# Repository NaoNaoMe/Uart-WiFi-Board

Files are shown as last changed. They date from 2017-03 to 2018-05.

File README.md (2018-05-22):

Uart WiFi Board
=========

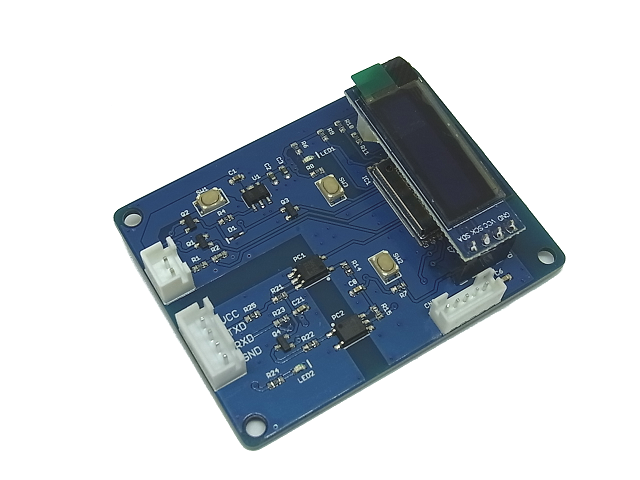
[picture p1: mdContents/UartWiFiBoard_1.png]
Uart WiFi Board
[  
*Uart WiFi Board(SKU-3849)*](https://international.switch-science.com/catalog/3849/)

## Uart WiFi Board has been launched! It is available in [the Switch Science store](https://international.switch-science.com/catalog/3849/).

The Uart WiFi Board designed as the transparent WiFi-serial bridge.  
There are some updates from the former Uart WiFi Board.  
 - The 128x32 pixels SSD1306 OLED display
 - The 3 user switches(a switch used as power switch too)

Thanks to add the 128x32 pixels OLED display, we can show IP address, SSID and Serial BaudRate.  
You don't need remember IP address and Baud Rate, you can see them in the display.
The Uart WiFi Board can be programmed using the Arduino IDE.

### Some highlights of the Uart WiFi Board:
 1. Main core: ESP-WROOM-02(ESP8266).
 2. Voltage regulator(3.3V) with control pin.
 3. Opto-isolated UART interface(Uart interface circuit accepts 3.3V and 5.0V).
 4. On board WiFi-controller can use following functions.
 	- LED1(IO2), SW1(IO12/POW_ON), SW2(IO16) and SW3(IO13)
 	- Control voltage regulator's control pin connected to "IO14" H:Enable L:Disable(normally)
 	- Voltage detection circuit(for CN1) connected to "TOUT"
 5. Measures 50mm x 60mm x 20mm

#### Some highlights of the Sample software:
 1. Totally transparent WiFi-serial bridge.
 2. IP address, SSID, Serial baud-rate and input-voltage can be displayed.
 3. Low voltage detection.
 
Sample software use the [esp8266-oled-ssd1306](https://github.com/ThingPulse/esp8266-oled-ssd1306) library.

Repository Contents
-------------------
* **/Hardware** - All Eagle design files (.brd, .sch)
* **/Software** - Software files for this hardware

Description(Pin Interfaces)
-------------------
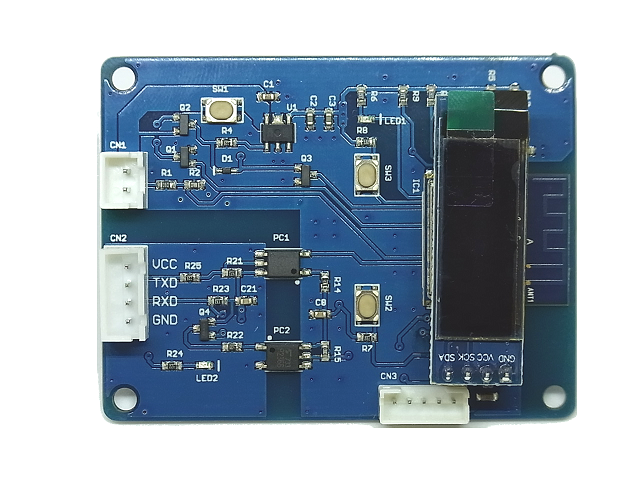
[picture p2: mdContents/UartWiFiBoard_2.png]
TopView


### CN1(Primarily) Pin Descriptions:
This connector is the supply voltage.

| Pin | Name | Description |
| --- | ---- | --- |
| 1 | VBAT | Up to 12.0VDC convert to 3.3VDC |
| 2 | GND  | GND	 |

### CN3(Primarily) Pin Descriptions:
This connector is for uploading software to WiFi-controller.  
To be selected BOOT MODE before supply voltage when you upload software.

| Pin | Name | Description |
| --- | ---- | --- |
| 1 | VCC  | 3.3VDC |
| 2 | TX | UART TX	 |
| 3 | RX | UART RX	 |
| 4 | GND  | GND	 |
| 5 | BOOT | Connected to "IO0" H:Flash boot(normally) L:UART download |

### CN2(Secondary) Pin Descriptions:
This connector is for your target board UART-interface.

| Pin | Name | Description |
| --- | ---- | --- |
| 1 | VIN  | 2.7VDC to 5.5VDC |
| 2 | TX | UART TX(Open collector output)	 |
| 3 | RX | UART RX	 |
| 4 | GND  | GND	 |

How to upload program
-------------------
See [this page](UploadProgram.md).

How to use the Uart WiFi Board
-------------------
An example is [here](Instructions.md).

License
-------------------
The repository is released under [Creative Commons ShareAlike 4.0 International](https://creativecommons.org/licenses/by-sa/4.0/).

Distributed as-is; no warranty is given.

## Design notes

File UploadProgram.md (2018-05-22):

Upload a program for the Uart WiFi Board
========================================

First of all
--------------
You will need the following items for uploading program.
 - FTDI Breakout Board(3.3V)
 - [FTDI Breakout Adapter](https://github.com/NaoNaoMe/FTDI-Breakout-Adapter)
 - [Programming cable](https://github.com/NaoNaoMe/FTDI-Breakout-Adapter/tree/master/Cables)

Hardware Setup
--------------
Connect the FTDI Breakout to the FTDI Breakout Adapter with the Programming cable like the following figure.
The JP1 on the FTDI Breakout Adapter is jumped to GND. The JP2 is not jumped.
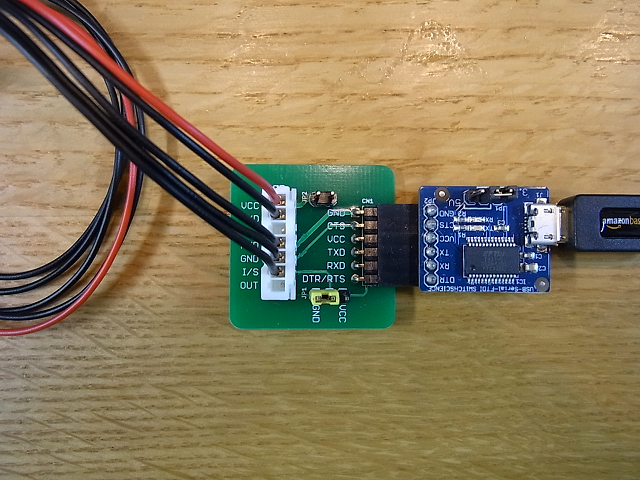
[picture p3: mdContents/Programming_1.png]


Upload a program
--------------
Plug the Programming cable into the CN2 on the Uart WiFi Board.  
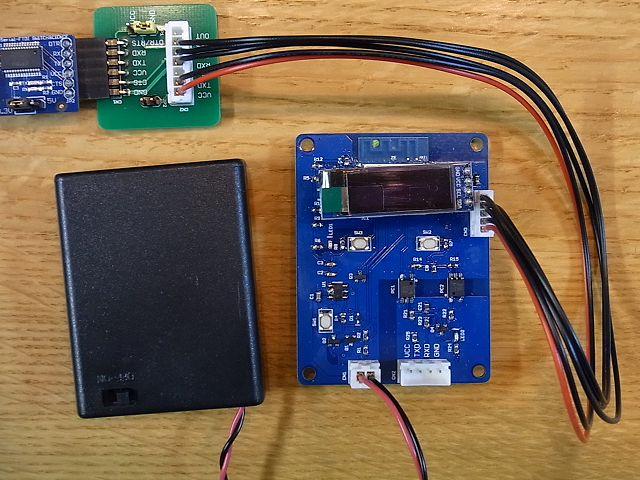
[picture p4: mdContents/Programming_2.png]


### Sample software
If you want to try [sample software](), you can modify the following configurations.
```
const char* ssid = "TestSSID0123";
const char* password = "TestEncryptionKey0123";

int serialSpeedIndex = 0;   //9600bps
```

### Arduino IDE
Open up [the sample software](https://github.com/NaoNaoMe/Uart-WiFi-Board/tree/with-display/Software/UartWiFiBridge) or your own software in the Arduino IDE.  
The board selection and programming configuration are in the figure below.  
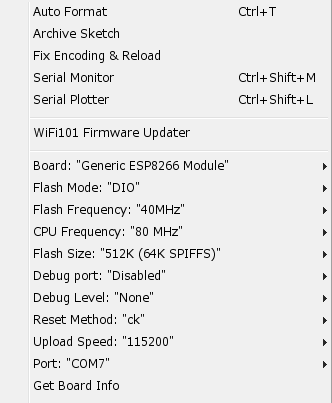
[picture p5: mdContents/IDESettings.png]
Settings
  

Press SW1 button in order to turn on the Uart WiFi Board. Please hold on SW1 button while uploading software.  
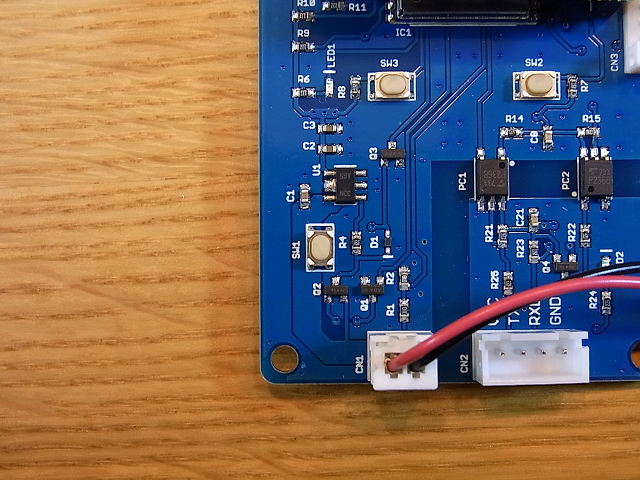
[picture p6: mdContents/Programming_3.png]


Click the Upload button in the IDE. Wait a few seconds.  
The message "Done uploading." will appear in the status bar, unplug the Programming cable from the Uart WiFi Board.

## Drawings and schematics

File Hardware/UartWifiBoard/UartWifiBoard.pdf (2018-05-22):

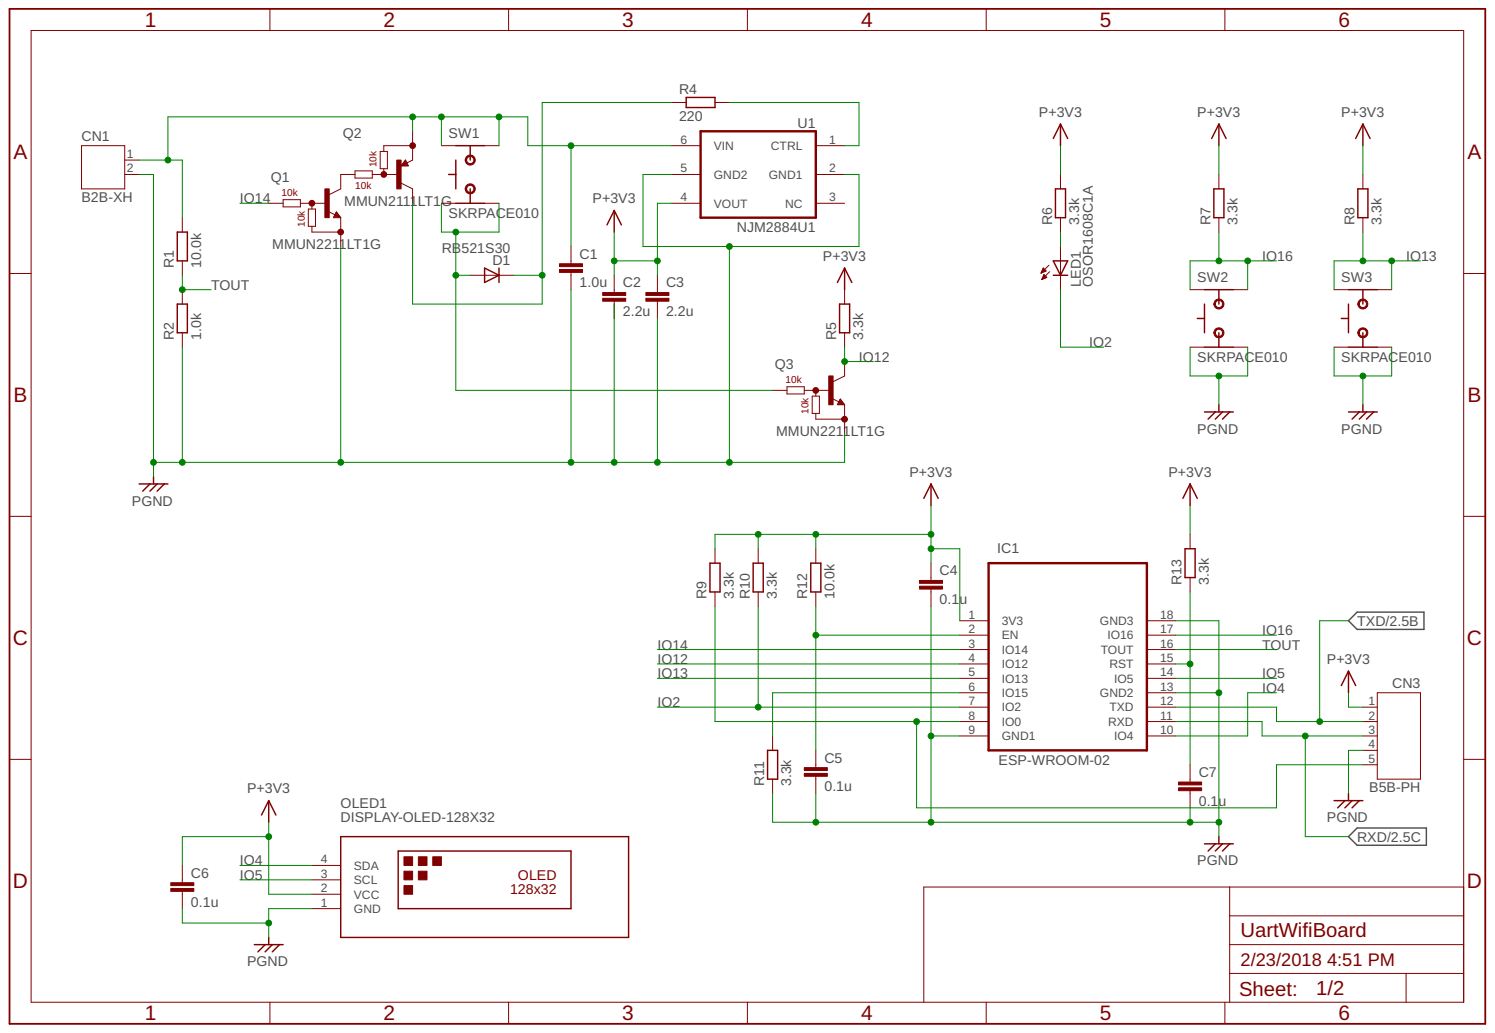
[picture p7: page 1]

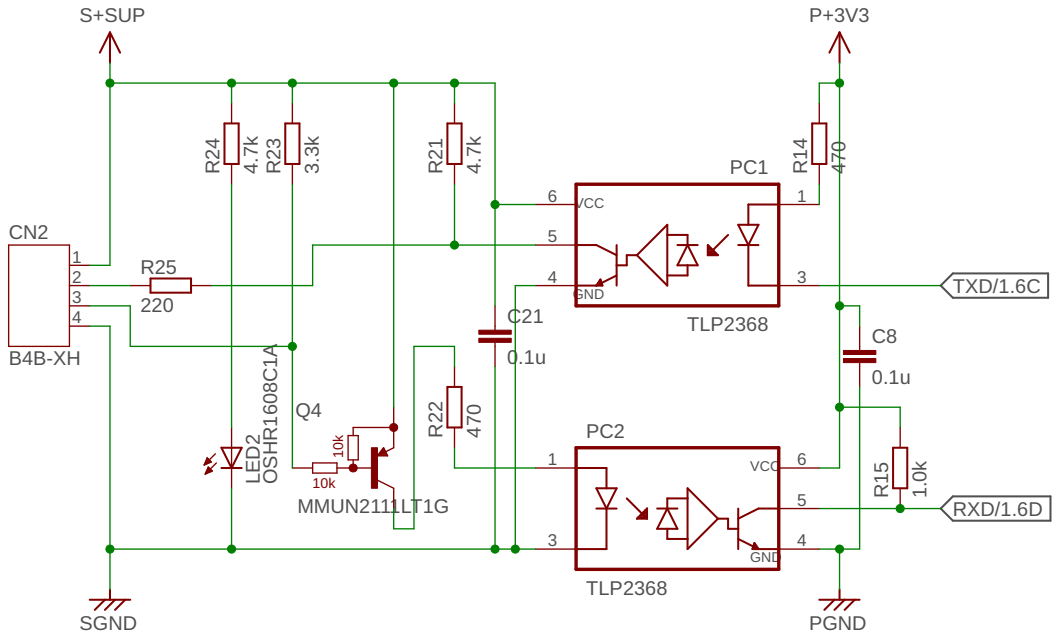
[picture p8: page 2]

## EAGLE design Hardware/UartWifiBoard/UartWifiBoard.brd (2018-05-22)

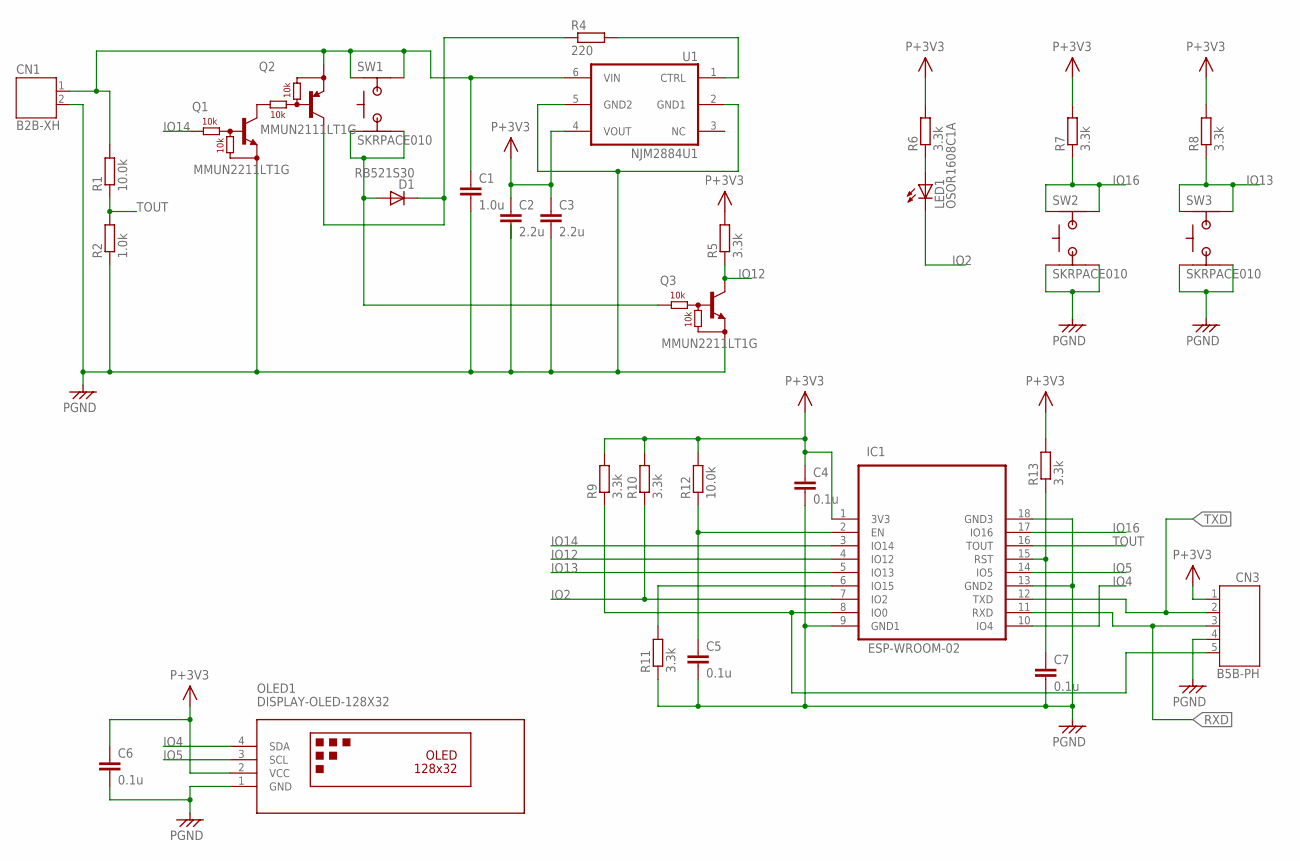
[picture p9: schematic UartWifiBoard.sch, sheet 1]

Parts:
C1: 1.0u; C0603
C2, C3: 2.2u; C0603
C4, C5, C6, C7: 0.1u; C0603
CN1: B2B-XH
CN3: B5B-PH
D1: RB521S30; SOD-523F
IC1: ESP-WROOM-02
LED1: OSOR1608C1A; LED0603SMD
OLED1: DISPLAY-OLED-128X32
Q1, Q3: MMUN2211LT1G; SOT-23
Q2: MMUN2111LT1G; SOT-23
R1, R12: 10.0k; R0603
R2: 1.0k; R0603
R4: 220; R0603
R5, R6, R7, R8, R9, R10, R11, R13: 3.3k; R0603
SW1, SW2, SW3: SKRPACE010; SKRP
U1: NJM2884U1; SOT89-5

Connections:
IO0: CN3.5, IC1.8 (IO0), R9.1
IO2: IC1.7 (IO2), LED1.C, R10.1
IO4: IC1.10 (IO4), OLED1.4 (SDA)
IO5: IC1.14 (IO5), OLED1.3 (SCL)
IO12: IC1.4 (IO12), Q3.P$3 (C), R5.1
IO13: IC1.5 (IO13), R8.1, SW3.1, SW3.2
IO14: IC1.3 (IO14), Q1.P$1 (B)
IO15: IC1.6 (IO15), R11.2
IO16: IC1.17 (IO16), R7.1, SW2.1, SW2.2
unnamed: Q1.P$3 (C), Q2.P$1 (B)
unnamed: R4.2, U1.1 (CTRL)
unnamed: C1.1, CN1.1, Q2.P$2 (E), R1.2, SW1.1, SW1.2, U1.6 (VIN)
unnamed: D1.C, Q2.P$3 (C), R4.1
unnamed: D1.A, Q3.P$1 (B), SW1.3, SW1.4
unnamed: C5.1, IC1.2 (EN), R12.1
unnamed: LED1.A, R6.1
P+3V3: C2.1, C3.1, C4.1, C6.1, CN3.1, IC1.1 (3V3), OLED1.2 (VCC), R5.2, R6.2, R7.2, R8.2, R9.2, R10.2, R12.2, R13.2, U1.4 (VOUT); also elsewhere on the board
PGND: C1.2, C2.2, C3.2, C4.2, C5.2, C6.2, C7.2, CN1.2, CN3.4, IC1.9 (GND1), IC1.13 (GND2), IC1.18 (GND3), OLED1.1 (GND), Q1.P$2 (E), Q3.P$2 (E), R2.1, R11.1, SW2.3, SW2.4, SW3.3, SW3.4, U1.2 (GND1), U1.5 (GND2); also elsewhere on the board
RST: C7.1, IC1.15 (RST), R13.1
RXD: CN3.3, IC1.11 (RXD); also elsewhere on the board
TOUT: IC1.16 (TOUT), R1.1, R2.2
TXD: CN3.2, IC1.12 (TXD); also elsewhere on the board

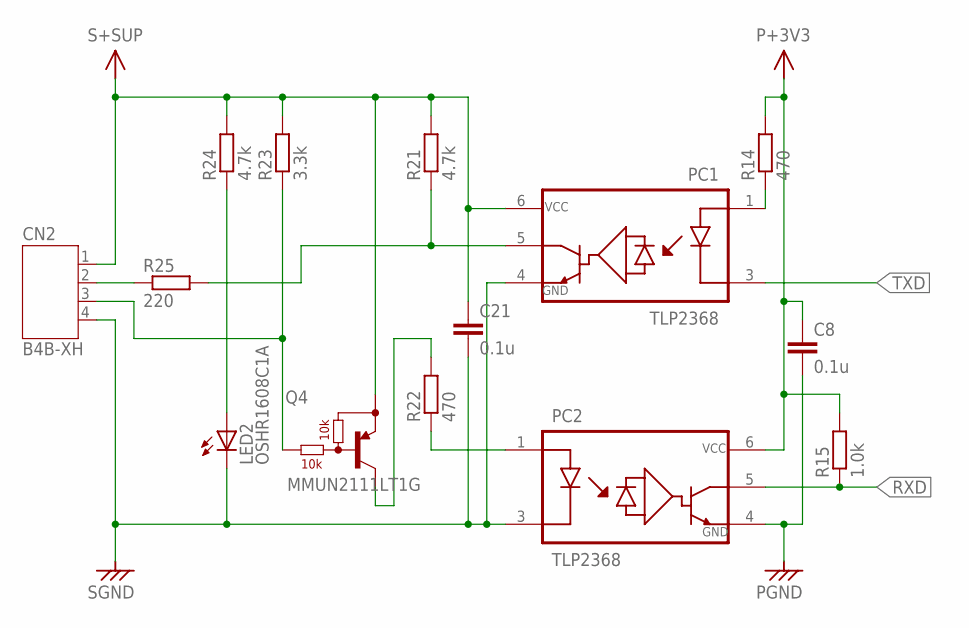
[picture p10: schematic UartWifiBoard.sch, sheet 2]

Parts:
C8, C21: 0.1u; C0603
CN2: B4B-XH
LED2: OSHR1608C1A; LED0603SMD
PC1, PC2: TLP2368; SO6-5PIN
Q4: MMUN2111LT1G; SOT-23
R14, R22: 470; R0603
R15: 1.0k; R0603
R21, R24: 4.7k; R0603
R23: 3.3k; R0603
R25: 220; R0603

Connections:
unnamed: Q4.P$3 (C), R22.2
unnamed: CN2.3, Q4.P$1 (B), R23.1
unnamed: PC2.1 (A), R22.1
unnamed: PC1.5 (VO), R21.1, R25.2
unnamed: CN2.2, R25.1
unnamed: LED2.A, R24.1
unnamed: PC1.1 (A), R14.1
P+3V3: C8.1, PC2.6 (VCC), R14.2, R15.2; also elsewhere on the board
PGND: C8.2, PC2.4 (GND); also elsewhere on the board
RXD: PC2.5 (VO), R15.1; also elsewhere on the board
S+SUP: C21.1, CN2.1, PC1.6 (VCC), Q4.P$2 (E), R21.2, R23.2, R24.2
SGND: C21.2, CN2.4, LED2.C, PC1.4 (GND), PC2.3 (K)
TXD: PC1.3 (K); also elsewhere on the board

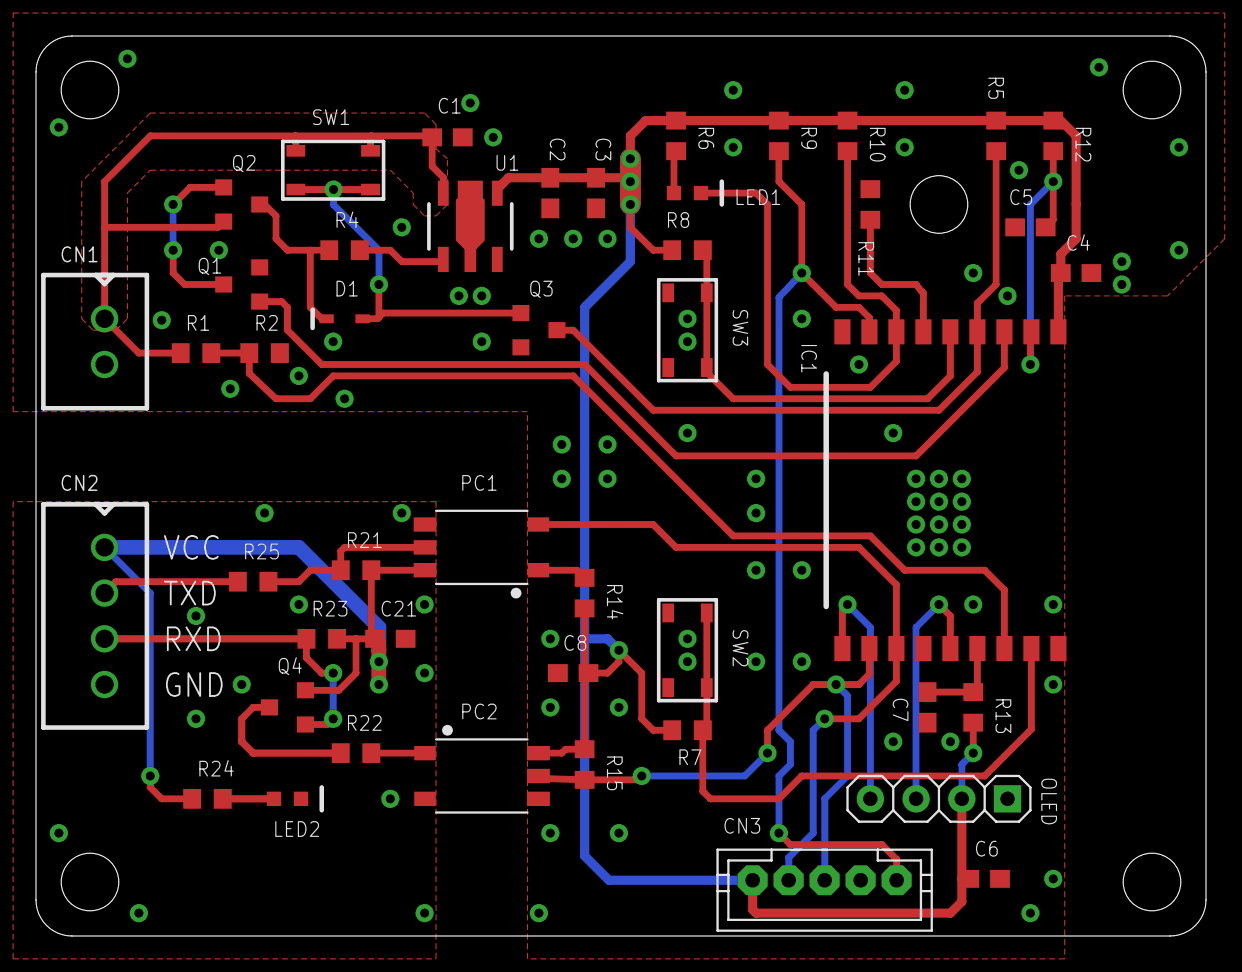
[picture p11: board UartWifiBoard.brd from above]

Board: 2 copper layers, 65.0 x 50.0 mm, 46 parts (0 on the bottom side), 31 nets.

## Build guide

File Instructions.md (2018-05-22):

How to use the Uart WiFi Board
========================================

The easiest way is using micro controller board which has arduino form-factor pinout.  

First of all
--------------
The Uart WiFi Board is programmed [Uart WiFi Bridge software](https://github.com/NaoNaoMe/Uart-WiFi-Board/tree/with-display/Software/UartWiFiBridge).  
You will need the following items for uploading program.
 - Arduino or Arduino form-factor board
 - [Communication Shield](https://github.com/NaoNaoMe/Communication-Shield)
 - [Communication cable](https://github.com/NaoNaoMe/Communication-Shield/tree/master/Cables)
 - PuTTY

Sample software for your board
--------------
These software serial configurations are 9600 bauds, 8-bit data and no parity.

Arduino
```
void setup() {
  Serial.begin(9600);
  Serial.println("Hello World !");
}

void loop() {
  if (Serial.available() > 0) {
    Serial.write(Serial.read() + 1);
  }
}
```

Mbed
```
#include "mbed.h"

Serial pc(D1, D0);  //for FRDM boards
//Serial pc(SERIAL_TX, SERIAL_RX);  // for Nucleo boards

int main() {
  pc.printf("Hello World !\n");
  while(1) {
    pc.putc(pc.getc() + 1);
  }
}
```

Hardware Setup
--------------
Attach the Communication shield in your micro-controller board. 

The Arduino UNO.

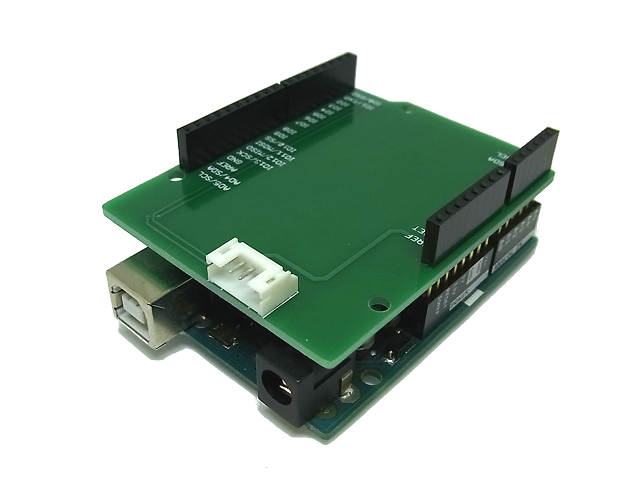
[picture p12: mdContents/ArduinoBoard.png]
Arduino


The Nucleo board.  
The Nucleo boards need some tricks about smd parts.  
All you need is that SB13 and SB14 are OFF, SB62 and SB63 are ON.

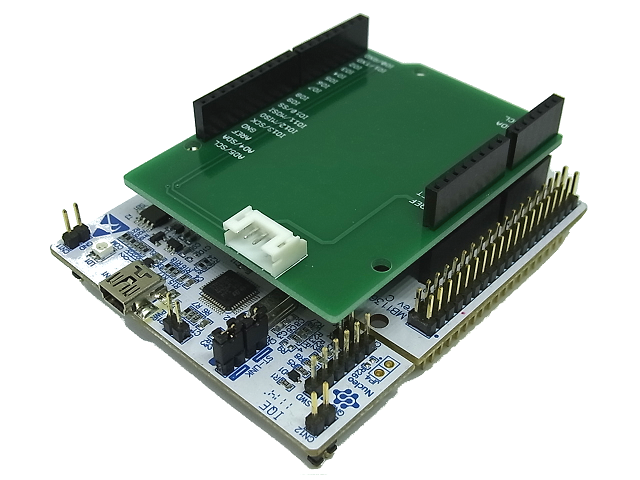
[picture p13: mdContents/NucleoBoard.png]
Nucleo


The FRDM board.

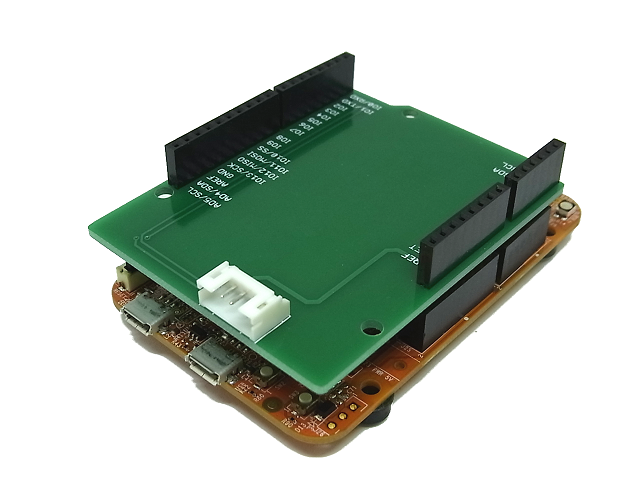
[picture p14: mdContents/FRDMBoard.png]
FRDM


Connect the Communication shield to the Uart WiFi Board with the Communication cable like the following figure(E.g. Arduino).

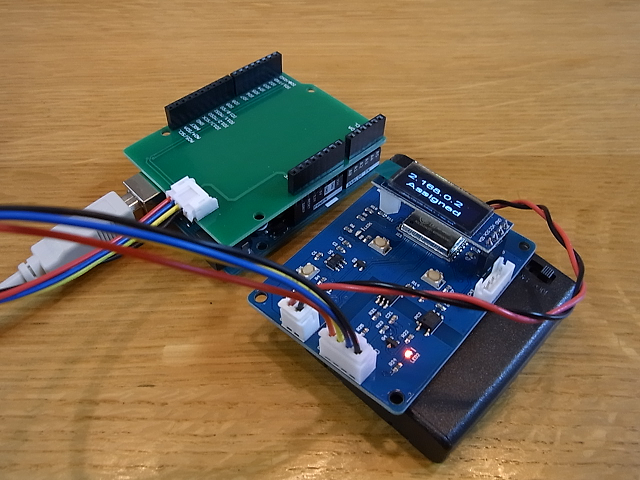
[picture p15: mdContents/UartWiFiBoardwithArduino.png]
Sample


Communication with your board
--------------
Press the SW1 button to turn on the Uart WiFi Board.  
The Uart WiFi Board is started, you can check SSID, IP address and baud rate on the display by pressing SW3 button.  

Execute PuTTY to start the application and type the IP address of the Uart WiFi Board in the Host Name field.  
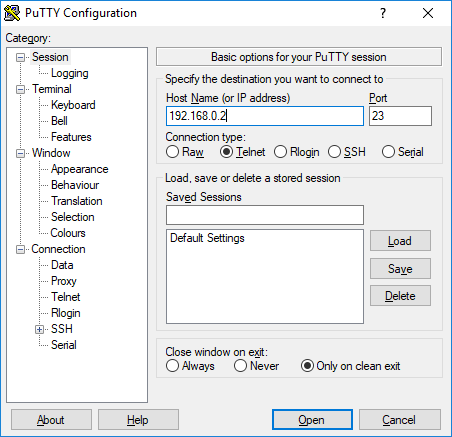
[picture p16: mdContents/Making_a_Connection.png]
Connection


Turn on your board. You can see "Hello World !" in the PuTTY application.
When you type a character, your board return a character like following.  
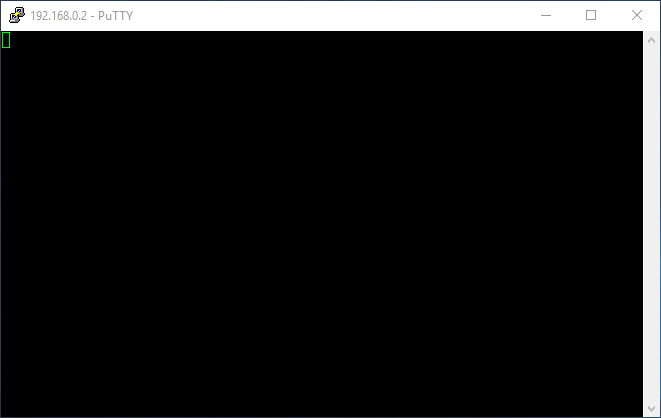
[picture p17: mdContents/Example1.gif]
Example


It looks like the cursor acts weird. That's because adding 1 to CR(0x0D) and LF(0x0A), they are changed to SO(0x0E) and VT(0x0B).

It doesn't work?
--------------
Please check bitrate on your board.  
In addition, you need to make sure that your computer are on the same network segment as the Uart WiFi Board.

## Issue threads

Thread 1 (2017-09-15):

Will it work for ESP 12 module?

Sumgit91, 2017-09-15:
Hi iam using ESP12 module and i need to transmit data from a sensor module which transmits data serially to appear in an interactive web page (which should act like a terminal program), will this code work for me?

NaoNaoMe, 2017-09-19:
If you connect esp-module to your sensor module, this code is not appropriate.
Almost all sensor modules communicate with I2C or SPI interface. This project only provide a UART interface.

Closed 2018-12-20.

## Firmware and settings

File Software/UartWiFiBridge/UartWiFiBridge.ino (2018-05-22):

//******************************************************************************
// UartWiFiBridge
// Note
// Totally transparent UART-WiFi bridge.
// This sketch adapts to UartWiFiBoard project.
//******************************************************************************

#include <ESP8266WiFi.h>
#include <Wire.h>
#include <EEPROM.h>
#include "oled.h"

#define POW_BUTTON_PIN 12   //SW1
#define LEFT_BUTTON_PIN 13  //SW3
#define RIGHT_BUTTON_PIN 16 //SW2

#define STATUS_LED_PIN 2  //LED1
#define REG_CTRL_PIN 14   //U1

#define SERIAL_ARRAY_SIZE 5

enum BoardCondition{
  CHECK_OLED_DEVICE = 0,
  BOARD_OPENING,
  WIFI_CONNECTION_WAITING,
  WIFI_CONNECTION_SUCCESS,
  BOARD_LV_DETECTED,
  BOARD_CLOSING
};

enum BoardProperty{
  SHOW_NOTHING = 0,
  SHOW_CONNECTED_SSID,
  SHOW_ASSIGNED_IP,
  SHOW_BAUDRATE,
  SHOW_BATTERY_VOLTAGE,
  SHOW_BLANK
};

enum SwitchState{
  SW_NOTHING = 0,
  SW_SHORT_PUSH,
  SW_LONG_PUSH
};

enum LvState{
  LV_NOTHING = 0,
  LV_DETECTED,
  LV_QUIT
};

#define RESISTOR_VALUE_R1  (float)10000  //10.0k ohm
#define RESISTOR_VALUE_R2  (float) 1000  // 1.0k ohm
#define IMPEDANCE_VALUE_AD (float)20000  //20.0k ohm

#define RESISTOR_VALUE_H    RESISTOR_VALUE_R1
#define RESISTOR_VALUE_L    (1/((1/RESISTOR_VALUE_R2) + (1/IMPEDANCE_VALUE_AD)))

#define BATT_GAIN_MAX       (float)100
#define BATT_GAIN_DEFAULT   (float)((RESISTOR_VALUE_L * 1024) / (RESISTOR_VALUE_H + RESISTOR_VALUE_L))
#define BATT_GAIN_MIN       (float)80

#define LV_DETECT_VOLTAGE     3.5f    // Low voltage value(3.5V)
#define LV_QUIT_VOLTAGE       3.3f    // Low voltage value(3.3V)

#define CALIBRATION_REF       5.0f    // Battery voltage value(5.0V)

//#define STATIC_IP_ADDR

const String SerialSpeeds[SERIAL_ARRAY_SIZE] = {
  "9600",
  "19200",
  "38400",
  "57600",
  "115200"
};

OLED OLEDModule;

const char VersionName[] = "UWB-Sample";
const char VersionNumber[] = "1.0.0";

const char* ssid = "TestSSID0123";
const char* password = "TestEncryptionKey0123";

#ifdef STATIC_IP_ADDR
IPAddress staticIP(192,168,0,25);
IPAddress gateway(192,168,0,1);
IPAddress subnet(255,255,255,0);
#endif

WiFiServer localServer(23); //Port number must be set
WiFiClient localClient;

int serialSpeedIndex = 0;
float BatteryCalcGain = BATT_GAIN_DEFAULT;
int   BattryVoltAD  = 0;
float BattryVoltage = 0;

LvState detectLowVoltage(){
  static unsigned long previousMillis = 0;
  static int lvDetectCnt = 0;
  static int lvQuitCnt = 0;
  static LvState lowVoltageState = LV_NOTHING;
  
  unsigned long currentMillis = millis();

  if ((currentMillis - previousMillis) >= 100) {
    previousMillis = currentMillis;

    //check Battery voltage
    BattryVoltAD = analogRead(A0);
    BattryVoltage = (float)BattryVoltAD / BatteryCalcGain;
    
    if( BattryVoltage < LV_DETECT_VOLTAGE ) {
      lvDetectCnt++;
    }
    else {
      lvDetectCnt = 0;      
    }
  
    if( lvDetectCnt > 10 ) {
      lvDetectCnt = 10;
      lowVoltageState = LV_DETECTED;
    }
    
    if( BattryVoltage < LV_QUIT_VOLTAGE ) {
      lvQuitCnt++;
    }
    else {
      lvQuitCnt = 0;      
    }
  
    if( lvQuitCnt > 10 ) {
      lvQuitCnt = 10;
      lowVoltageState = LV_QUIT;
    }
  }
  
  return lowVoltageState;
}

bool IntervalTiming(int intervalCount){
  static unsigned long previousMillis = 0;

  bool timeupFlg = false;
  
  unsigned long currentMillis = millis();
  
  if ((currentMillis - previousMillis) >= intervalCount) {
    previousMillis = currentMillis;
    timeupFlg = true;

  }
  
  return timeupFlg;
}


SwitchState detectLeftButton(){
  static unsigned long previousMillis = 0;
  static SwitchState swState = SW_NOTHING;
  SwitchState retState = SW_NOTHING;
  unsigned long currentMillis = millis();
  
  int val = digitalRead(LEFT_BUTTON_PIN);
  if(val == LOW)
  {
    if ((currentMillis - previousMillis) > 1000) {
      if( swState != SW_LONG_PUSH ){
        swState = SW_LONG_PUSH;
        retState = SW_LONG_PUSH;
        
      }

    }
    else if ((currentMillis - previousMillis) > 100) {
      swState = SW_SHORT_PUSH;

    }
  }
  else
  {
    if(swState == SW_SHORT_PUSH) {
      retState = SW_SHORT_PUSH;
      swState = SW_NOTHING;
      
    }

    previousMillis = currentMillis;
    
  }

  return retState;
}


SwitchState detectRightButton(){
  static unsigned long previousMillis = 0;
  static SwitchState swState = SW_NOTHING;
  SwitchState retState = SW_NOTHING;
  unsigned long currentMillis = millis();
  
  int val = digitalRead(RIGHT_BUTTON_PIN);
  if(val == LOW)
  {
    if ((currentMillis - previousMillis) > 1000) {
      if( swState != SW_LONG_PUSH ){
        swState = SW_LONG_PUSH;
        retState = SW_LONG_PUSH;
        
      }

    }
    else if ((currentMillis - previousMillis) > 100) {
      swState = SW_SHORT_PUSH;

    }
  }
  else
  {
    if(swState == SW_SHORT_PUSH) {
      retState = SW_SHORT_PUSH;
      swState = SW_NOTHING;
      
    }

    previousMillis = currentMillis;
    
  }

  return retState;
}

bool detectPowButton(){
  static unsigned long previousMillis = 0;
  bool retFlg = false;
  unsigned long currentMillis = millis();
  
  int val = digitalRead(POW_BUTTON_PIN);
  if(val == LOW)
  {
    if (currentMillis - previousMillis > 3000) {
      previousMillis = currentMillis;
      retFlg = true;
    }
  }
  else
  {
    previousMillis = currentMillis;
    
  }

  return retFlg;
}

String appendString(String stringOne, String stringTwo ) {
  String retString;
  retString = stringOne.concat(stringTwo);
  return stringOne;
}

void dataExchange() {
  static unsigned long previousMillis = 0;
  
  unsigned long currentMillis = millis();
  if ((currentMillis - previousMillis) >= 50) {
    previousMillis = currentMillis;
    size_t bufLength = 0;
    
    //check if there are any new clients
    if (localServer.hasClient()){
      if (!localClient.connected()){
        if(localClient){
          localClient.stop();
        }
        localClient = localServer.available();
      }
    }
    
    //check a client to bridge UART
    if (localClient && localClient.connected()){
      if(localClient.available()){
        bufLength = localClient.available();
        uint8_t sbuf[bufLength];
        localClient.readBytes(sbuf, bufLength);
        Serial.write(sbuf, bufLength);
      }
      digitalWrite(STATUS_LED_PIN, LOW);
    }
    else{
      digitalWrite(STATUS_LED_PIN, HIGH);
      
    }

    //check UART to bridge WiFi
    if(Serial.available()){
      bufLength = Serial.available();
      uint8_t sbuf[bufLength];
      Serial.readBytes(sbuf, bufLength);
      if (localClient && localClient.connected()){
        localClient.write(sbuf, bufLength);
      }
    }
  }
}

bool ScanI2CDevices(byte address) {
  bool retflg =false;
  Wire.beginTransmission(address);
  byte error = Wire.endTransmission();
  if (error == 0) {
    retflg = true;
    
  }
  return retflg;
}

float ReadCalibration(float input) {
  float output = input;
  float gain = 0;
  byte tmp = 0;
  uint32_t value = 0;
  
  tmp = EEPROM.read(3);
  value |= (uint32_t)tmp;
  value = (value << 8) & 0xFFFFFF00;
  tmp = EEPROM.read(2);
  value |= (uint32_t)tmp;
  value = (value << 8) & 0xFFFFFF00;
  tmp = EEPROM.read(1);
  value |= (uint32_t)tmp;
  value = (value << 8) & 0xFFFFFF00;
  tmp = EEPROM.read(0);
  value |= (uint32_t)tmp;

  if(value != 0xFFFFFFFF) {
    gain = *(float *)&value;
    if( (gain <  BATT_GAIN_MAX) &&
        (gain >= BATT_GAIN_MIN) ) {
      output = gain;
    }
  }
  
  return output;
}

float WriteCalibration(float input) {
  float output = input;
  byte tmp = 0;
  uint32_t value = 0;

  if( (input >= BATT_GAIN_MAX) ||
      (input <  BATT_GAIN_MIN) ) {
    return output;
  }
  
  value = *(uint32_t *)&input;
  tmp = (byte)(value & 0x000000FF); 
  value = value >> 8;
  EEPROM.write(0, tmp);
  tmp = (byte)(value & 0x000000FF); 
  value = value >> 8;
  EEPROM.write(1, tmp);
  tmp = (byte)(value & 0x000000FF); 
  value = value >> 8;
  EEPROM.write(2, tmp);
  tmp = (byte)(value & 0x000000FF); 
  EEPROM.write(3, tmp);

  EEPROM.commit();
  
  return output;
}

void setup() {
  digitalWrite(REG_CTRL_PIN, HIGH);   // Enable to external voltage regulator.
  digitalWrite(STATUS_LED_PIN, HIGH);

  pinMode(REG_CTRL_PIN, OUTPUT);
  pinMode(STATUS_LED_PIN, OUTPUT);
  
  pinMode(POW_BUTTON_PIN, INPUT);
  pinMode(LEFT_BUTTON_PIN, INPUT);
  pinMode(RIGHT_BUTTON_PIN, INPUT);

  Wire.begin();

  Serial.begin(SerialSpeeds[serialSpeedIndex].toInt());
  
  WiFi.begin(ssid, password);
#ifdef STATIC_IP_ADDR
  WiFi.config(staticIP, gateway, subnet);
#endif

  EEPROM.begin(4);

  BatteryCalcGain = ReadCalibration(BatteryCalcGain);

  IntervalTiming(0);

}

void loop() {
  static BoardCondition wifiState = CHECK_OLED_DEVICE;
  String firstColumn;
  String secondColumn;
  
  switch(wifiState){
    case CHECK_OLED_DEVICE:
      if(IntervalTiming(100)) {
        if(ScanI2CDevices(0x3c)) {
          wifiState = BOARD_OPENING;
          OLEDModule.initialize();
          IntervalTiming(0);
          //Serial.println("OLED device found");
        }
        else {
          //Serial.println("There are no OLED devices");          
        }
      }

    break;
    
    case BOARD_OPENING:
      firstColumn = String(VersionName);
      secondColumn = String(VersionNumber);
      OLEDModule.drawDisplayWithScrolling(firstColumn, secondColumn, false);

      if(IntervalTiming(2000)){
        wifiState = WIFI_CONNECTION_WAITING;
      }
      
    break;

    case WIFI_CONNECTION_WAITING:
      firstColumn = String(ssid);
      secondColumn = "Connecting";
      OLEDModule.drawDisplayWithScrolling(firstColumn, secondColumn, false);
      
      if(WiFi.status() == WL_CONNECTED){
        wifiState = WIFI_CONNECTION_SUCCESS;
        
        localServer.begin();
        localServer.setNoDelay(true);
        
        IntervalTiming(0);
        
      }
      
    break;

    case WIFI_CONNECTION_SUCCESS:

      displaySequence();
      
      if(WiFi.status() == WL_CONNECTED){
        dataExchange();
      }
      else{
        wifiState = WIFI_CONNECTION_WAITING;
      }

      {
        LvState tmpState = detectLowVoltage();
        if(tmpState == LV_DETECTED){
          wifiState = BOARD_LV_DETECTED;
          WiFi.disconnect();
          Serial.end();
        }
        else if(tmpState == LV_QUIT){
          wifiState = BOARD_CLOSING;
        }
      }
	  
    break;

    case BOARD_LV_DETECTED:
      firstColumn = "LV Detected";
      char buff[10];
      dtostrf(BattryVoltage, 4, 2, buff);  //4 is mininum width, 2 is precision
      secondColumn = appendString(String(buff),String("V"));
      OLEDModule.drawDisplayCenterAligned(firstColumn, secondColumn );
      
      if(detectLowVoltage() == LV_QUIT){
        wifiState = BOARD_CLOSING;
      }
    break;
    
    case BOARD_CLOSING:
      firstColumn = "POWER";
      secondColumn = "OFF";
      OLEDModule.drawDisplayCenterAligned(firstColumn, secondColumn);
      WiFi.disconnect();
      
      if(IntervalTiming(2000)){
        digitalWrite(REG_CTRL_PIN, LOW);   // External voltage regulator will be stopped.
      }
      
    break;

    default:
      
    break;
    
  }

  if(detectPowButton()){
    wifiState = BOARD_CLOSING;
  }
  
}

void displaySequence(void){
  static BoardProperty currentProperty = SHOW_CONNECTED_SSID;
  static BoardProperty previousProperty = SHOW_CONNECTED_SSID;
  static bool blinkFlg = false;
  String firstColumn;
  String secondColumn;

  switch(currentProperty){
    case SHOW_CONNECTED_SSID:
      firstColumn = String(ssid);
      secondColumn = "Connected";
      OLEDModule.drawDisplayWithScrolling(firstColumn, secondColumn, false);

      if(IntervalTiming(5000)){
        previousProperty = currentProperty;
        currentProperty = SHOW_BLANK;
      }

      if( detectLeftButton() == SW_SHORT_PUSH){
        currentProperty = SHOW_ASSIGNED_IP;
      }
      
    break;

    case SHOW_ASSIGNED_IP:
      firstColumn = WiFi.localIP().toString();
      secondColumn = "Assigned";
      OLEDModule.drawDisplayWithScrolling(firstColumn, secondColumn, false);
      
      if(IntervalTiming(5000)){
        previousProperty = currentProperty;
        currentProperty = SHOW_BLANK;
      }

      if( detectLeftButton() == SW_SHORT_PUSH){
        currentProperty = SHOW_BAUDRATE;
        IntervalTiming(0);
        blinkFlg = false;
      }
      
    break;
      
    case SHOW_BAUDRATE:
      firstColumn = appendString(SerialSpeeds[serialSpeedIndex],String("bps"));
      secondColumn = "Serial Data rate";

      if( blinkFlg == false ){
        OLEDModule.drawDisplayWithScrolling(firstColumn, secondColumn, false);

        SwitchState tmpState = detectLeftButton();
        detectRightButton();  //Dummy call
        
        if( tmpState == SW_LONG_PUSH){
          blinkFlg = true;
          IntervalTiming(0);
        }
        
        if( tmpState == SW_SHORT_PUSH){
          currentProperty = SHOW_BATTERY_VOLTAGE;
          IntervalTiming(0);
        }
        
      }
      else {
        OLEDModule.drawDisplayWithScrolling(firstColumn, secondColumn, true);
        
        if( detectRightButton() == SW_SHORT_PUSH){
          serialSpeedIndex++;
          if( serialSpeedIndex >= SERIAL_ARRAY_SIZE){
            serialSpeedIndex = 0;
          }
          IntervalTiming(0);
        }
        
        if( detectLeftButton() == SW_LONG_PUSH){
          blinkFlg = false;
          IntervalTiming(0);

          Serial.end();
          delay(200);
          Serial.begin(SerialSpeeds[serialSpeedIndex].toInt());
          
        }
        
      }

      if(IntervalTiming(5000)){
        previousProperty = currentProperty;
        currentProperty = SHOW_BLANK;
        blinkFlg = false;
      }

    break;

    case SHOW_BATTERY_VOLTAGE:
      firstColumn = "BATT Volt";
      char buff[10];
      dtostrf(BattryVoltage, 4, 2, buff);  //4 is mininum width, 2 is precision
      secondColumn = appendString(String(buff),String("V"));
      OLEDModule.drawDisplayCenterAligned(firstColumn, secondColumn );
      
      if(IntervalTiming(5000)){
        previousProperty = currentProperty;
        currentProperty = SHOW_BLANK;
      }

      if( detectLeftButton() == SW_SHORT_PUSH){
        currentProperty = SHOW_CONNECTED_SSID;
        IntervalTiming(0);
      }
      
      if( detectRightButton() == SW_LONG_PUSH){
        //VBAT(CN1) Voltage Calibration
        BatteryCalcGain = (float)BattryVoltAD / CALIBRATION_REF;
        BatteryCalcGain = WriteCalibration(BatteryCalcGain);
        IntervalTiming(0);
      }
      
    break;

    case SHOW_BLANK:
      OLEDModule.clear();
      currentProperty = SHOW_NOTHING;
    break;

    default:
      if( detectLeftButton() == SW_SHORT_PUSH){
        currentProperty = previousProperty;
        IntervalTiming(0);
      }
      
    break;
    
  }

}

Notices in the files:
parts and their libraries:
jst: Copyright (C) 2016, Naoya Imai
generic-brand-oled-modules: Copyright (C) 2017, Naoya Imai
